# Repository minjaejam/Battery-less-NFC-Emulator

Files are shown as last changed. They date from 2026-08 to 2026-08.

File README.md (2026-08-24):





https://github.com/user-attachments/assets/a0f929fd-fd86-4b5f-9a33-4b0fc378b6a2

https://github.com/user-attachments/assets/47e20b58-1ad2-490b-87c6-6bac8df01a59

■ 주요 기능
1. 배터리 없이 동작
2. 13.56 MHz NFC 통신
3. MCU 기반 NFC 태그 에뮬레이션
4. ISO/IEC 14443 Type A 통신
5. PCB Loop Antenna 사용

■ 현재 지원
1. mifare classic 1k
2. ntag215 (시연을 위해 닌텐도 스위치 amiibo 데이터를 이용)

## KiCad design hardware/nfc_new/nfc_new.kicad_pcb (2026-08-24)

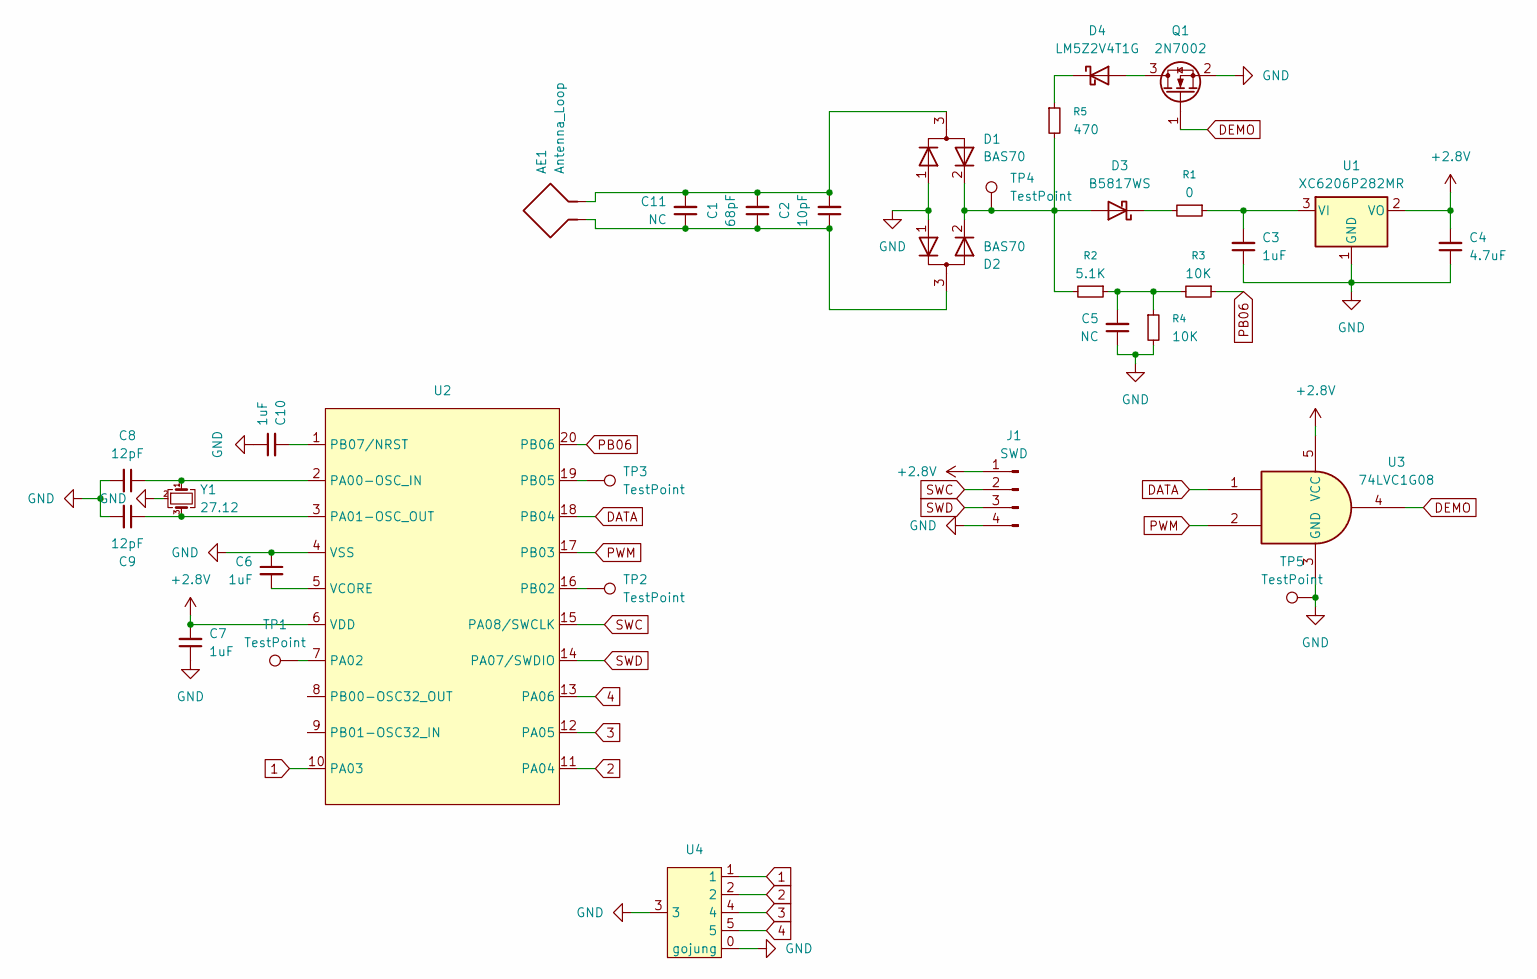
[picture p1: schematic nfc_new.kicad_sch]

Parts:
AE1: Antenna_Loop; 1.8uH_2
C1: 68pF; C_0805_2012Metric_Pad1.18x1.45mm_HandSolder
C2: 10pF; C_0805_2012Metric_Pad1.18x1.45mm_HandSolder
C3, C6, C7, C10: 1uF; C_0805_2012Metric_Pad1.18x1.45mm_HandSolder
C4: 4.7uF; C_0805_2012Metric_Pad1.18x1.45mm_HandSolder
C5, C11: NC; C_0805_2012Metric_Pad1.18x1.45mm_HandSolder
C8, C9: 12pF; C_0805_2012Metric_Pad1.18x1.45mm_HandSolder
D1, D2: BAS70; SOT-323_SC-70
D3: B5817WS; D_SOD-323_HandSoldering
D4: LM5Z2V4T1G; D_SOD-523
J1: SWD; PinHeader_1x04_P2.54mm_Vertical
Q1: 2N7002; SOT-23
R1: 0; R_0805_2012Metric_Pad1.20x1.40mm_HandSolder
R2: 5.1K; R_0805_2012Metric_Pad1.20x1.40mm_HandSolder
R3, R4: 10K; R_0805_2012Metric_Pad1.20x1.40mm_HandSolder
R5: 470; R_0805_2012Metric_Pad1.20x1.40mm_HandSolder
TP1, TP2, TP3, TP4, TP5: TestPoint; TestPoint_Pad_D1.0mm
U1: XC6206P282MR; SOT-23-3
U2: QFN-20-1EP_3x3mm_P0.4mm_EP1.65x1.65mm_ThermalVias
U3: 74LVC1G08; SOT-23-5_HandSoldering
U4: spd4
Y1: 27.12; Crystal_SMD_3225-4Pin_3.2x2.5mm_HandSoldering

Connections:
1: U2.10 (PA03), U4.1
2: U2.11 (PA04), U4.2
3: U2.12 (PA05), U4.4
4: U2.13 (PA06), U4.5
+2.8V: C4.2, C7.2, J1.1, U1.2 (VO), U2.6 (VDD), U3.5 (VCC)
DATA: U2.18 (PB04), U3.1
DEMO: Q1.1 (G), U3.4
GND: C3.1, C4.1, C5.1, C6.1, C7.1, C8.2, C9.2, C10.1, D1.1 (A), D2.1 (A), J1.4, Q1.2 (S), R4.2, TP5.1 (1_1), U1.1 (GND), U2.4 (VSS), U2.21 (VSS), U3.3 (GND), U4.0 (gojung), U4.3, Y1.2 (G), Y1.4 (G)
unnamed: C5.2, R2.1, R3.2, R4.1
unnamed: D1.2 (K), D2.2 (K), D3.2 (A), R2.2, R5.2, TP4.1 (1_1)
unnamed: AE1.2, C1.2, C2.2, C11.2, D1.3 (common)
unnamed: AE1.1, C1.1, C2.1, C11.1, D2.3 (common)
unnamed: D3.1 (K), R1.2
unnamed: D4.2 (A), Q1.3 (D)
unnamed: D4.1 (K), R5.1
unnamed: C3.2, R1.1, U1.3 (VI)
unnamed: C8.1, U2.2 (PA00-OSC_IN), Y1.1
unnamed: C9.1, U2.3 (PA01-OSC_OUT), Y1.3
unnamed: TP1.1 (1_1), U2.7 (PA02)
unnamed: TP2.1 (1_1), U2.16 (PB02)
unnamed: TP3.1 (1_1), U2.19 (PB05)
unnamed: C10.2, U2.1 (PB07/NRST)
unnamed: C6.2, U2.5 (VCORE)
PB06: R3.1, U2.20 (PB06)
PWM: U2.17 (PB03), U3.2
SWC: J1.2, U2.15 (PA08/SWCLK)
SWD: J1.3, U2.14 (PA07/SWDIO)

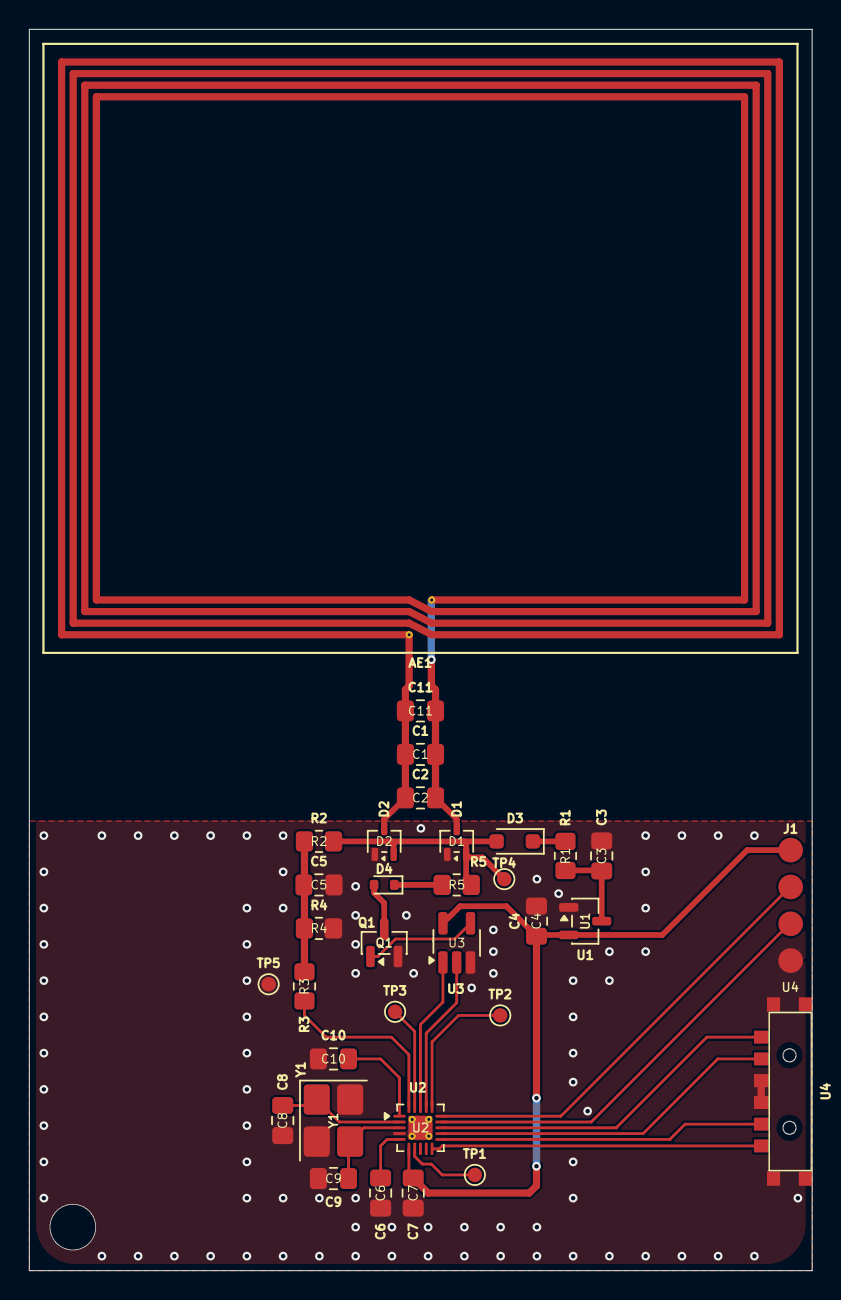
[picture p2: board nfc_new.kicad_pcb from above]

Board: 2 copper layers, 54.0 x 85.6 mm, 33 parts (0 on the bottom side), 27 nets.

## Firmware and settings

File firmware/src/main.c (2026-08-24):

#include <stddef.h>
#include <stdint.h>

#include "../inc/mifare_classic.h"
#include "../inc/tag_emulator.h"
#include "cw32l010.h"

#define REG32(address) (*(volatile uint32_t *)(uintptr_t)(address))

#define VC_DIV_REG          ((uintptr_t)&CW_VCREF->CR)
#define VC2_CR0_REG         ((uintptr_t)&CW_VC2->CR0)
#define VC2_CR1_REG         ((uintptr_t)&CW_VC2->CR1)
#define VC2_SR_REG          ((uintptr_t)&CW_VC2->SR)

#define NVIC_ISER0_REG      0xE000E100u
#define NVIC_ICPR0_REG      0xE000E280u
#define VC2_IRQ_MASK        (1u << 15)

#define SYSCTRL_CR0_REG     ((uintptr_t)&CW_SYSCTRL->CR0)
#define SYSCTRL_CR1_REG     ((uintptr_t)&CW_SYSCTRL->CR1)
#define SYSCTRL_HSE_REG     ((uintptr_t)&CW_SYSCTRL->HSE)
#define SYSCTRL_AHBEN_REG   ((uintptr_t)&CW_SYSCTRL->AHBEN)
#define SYSCTRL_APBEN2_REG  ((uintptr_t)&CW_SYSCTRL->APBEN2)
#define SYSCTRL_APBEN1_REG  ((uintptr_t)&CW_SYSCTRL->APBEN1)
#define SYSCTRL_HSE_STABLE  (1u << 19)
#define HSE_WAIT_FOR_STABLE 0
#define HSE_STARTUP_PDRIVER 7u
#define HSE_FAST_CONFIG     (0x00012605u | (HSE_STARTUP_PDRIVER << 20))


#define BTIM1_CR1_REG       ((uintptr_t)&CW_BTIM1->CR1)
#define BTIM1_ICR_REG       ((uintptr_t)&CW_BTIM1->ICR)
#define BTIM1_CNT_REG       ((uintptr_t)&CW_BTIM1->CNT)

#define GTIM1_CR1_REG       ((uintptr_t)&CW_GTIM1->CR1)
#define GTIM1_CCMR2CMP_REG  ((uintptr_t)&CW_GTIM1->CCMR2CMP)
#define GTIM1_CCER_REG      ((uintptr_t)&CW_GTIM1->CCER)
#define GTIM1_CNT_REG       ((uintptr_t)&CW_GTIM1->CNT)
#define GTIM1_PSC_REG       ((uintptr_t)&CW_GTIM1->PSC)
#define GTIM1_ARR_REG       ((uintptr_t)&CW_GTIM1->ARR)
#define GTIM1_CCR4_REG      ((uintptr_t)&CW_GTIM1->CCR4)

#define GPIOA_DIR_REG       ((uintptr_t)&CW_GPIOA->DIR)
#define GPIOA_OPENDRAIN_REG ((uintptr_t)&CW_GPIOA->OPENDRAIN)
#define GPIOA_PUR_REG       ((uintptr_t)&CW_GPIOA->PUR)
#define GPIOA_AFRL_REG      ((uintptr_t)&CW_GPIOA->AFRL)
#define GPIOA_ANALOG_REG    ((uintptr_t)&CW_GPIOA->ANALOG)
#define GPIOA_IDR_REG       ((uintptr_t)&CW_GPIOA->IDR)
#define GPIOA_BRR_REG       ((uintptr_t)&CW_GPIOA->BRR)

#define GPIOB_DIR_REG       ((uintptr_t)&CW_GPIOB->DIR)
#define GPIOB_OPENDRAIN_REG ((uintptr_t)&CW_GPIOB->OPENDRAIN)
#define GPIOB_AFRL_REG      ((uintptr_t)&CW_GPIOB->AFRL)
#define GPIOB_ANALOG_REG    ((uintptr_t)&CW_GPIOB->ANALOG)
#define GPIOB_BRR_REG       ((uintptr_t)&CW_GPIOB->BRR)

/* The scatter file fixes these objects because the recovered PHY uses them. */
uint32_t SystemCoreClock
    __attribute__((section(".bss.noinit.SystemCoreClock"), used));
NfcRuntime g_nfc_state
    __attribute__((section(".bss.noinit.g_nfc_state"), used));
typedef char nfc_runtime_size_check[(sizeof(NfcRuntime) == 0x108u) ? 1 : -1];
typedef char nfc_rx_offset_check[(offsetof(NfcRuntime, rx) == 8u) ? 1 : -1];

static void system_clock_start_hse(void)
{
    /* Start the crystal first, then do useful initialization while it locks. */
    REG32(SYSCTRL_AHBEN_REG) |= 0x30u;
    REG32(GPIOA_ANALOG_REG) = 3u;
    REG32(SYSCTRL_HSE_REG) = HSE_FAST_CONFIG;
    REG32(SYSCTRL_CR1_REG) |= 0x5A5A0182u;

    /* Make GPIO, GTIM1 and VC registers available during the HSE start-up. */
    REG32(SYSCTRL_AHBEN_REG) = 0x5A5A0032u;
    REG32(SYSCTRL_APBEN1_REG) = 0x5A5A0042u;
    REG32(SYSCTRL_APBEN2_REG) = 0x5A5A0004u;
}

static void system_clock_finish_hse(void)
{
#if HSE_WAIT_FOR_STABLE
    /* 8192 detected HSE clocks are required before the timing-source switch. */
    while ((REG32(SYSCTRL_HSE_REG) & SYSCTRL_HSE_STABLE) == 0u) {
    }
#endif

    REG32(SYSCTRL_CR0_REG) =
        (((REG32(SYSCTRL_CR0_REG) & 0xFFFFu) + 0x5A5A0000u) & ~7u) | 1u;
    SystemCoreClock = 27120000u;
    REG32(SYSCTRL_CR1_REG) =
        (((REG32(SYSCTRL_CR1_REG) & 0xFFFFu) + 0x5A5A0000u) & ~1u);
}

static void io_init(void)
{
    uint32_t selector;

    /* PB5/PB6 are unused analog inputs; do not power the former UART pins. */
    REG32(GPIOB_ANALOG_REG) = 0x60u;
    REG32(GPIOB_DIR_REG) = 0u;
    REG32(GPIOB_OPENDRAIN_REG) = 0u;
    REG32(GPIOB_BRR_REG) |= 0x18u;

    REG32(GPIOA_ANALOG_REG) &= ~0x7Cu;
    REG32(GPIOA_PUR_REG) |= 0x78u;
    REG32(GPIOA_DIR_REG) = (REG32(GPIOA_DIR_REG) & ~0x04u) | 0x78u;
    REG32(GPIOA_OPENDRAIN_REG) &= ~0x04u;
    REG32(GPIOA_BRR_REG) = 0x04u;

    selector = REG32(GPIOA_IDR_REG) & 0x78u;
    REG32((uintptr_t)&g_nfc_state) = 0x01000000u;
    g_nfc_state.printf_state = 0u;

    /* Patterns are written in PA3, PA4, PA5, PA6 order. */
    switch (selector) {
    case 0x70u: /* 0,1,1,1: PA3 low */
        g_nfc_state.slot = 4u;
        break;
    case 0x68u: /* 1,0,1,1: PA4 low */
        g_nfc_state.slot = 5u;
        break;
    case 0x58u: /* 1,1,0,1: PA5 low */
        g_nfc_state.slot = 6u;
        break;
    case 0x38u: /* 1,1,1,0: PA6 low */
        g_nfc_state.slot = 7u;
        break;
    default:
        g_nfc_state.slot = 4u;
        g_nfc_state.selector_valid = 0u;
        break;
    }

    /* The one-hot selector is latched. Remove its static pull-up current. */
    REG32(GPIOA_PUR_REG) &= ~0x78u;
    REG32(GPIOA_ANALOG_REG) |= 0x78u;

    REG32(GPIOB_AFRL_REG) =
        (REG32(GPIOB_AFRL_REG) & 0xFFFFF8FFu) + 0x00000400u;
}

static void nfc_config_typea_timing(void)
{
    REG32(GPIOB_AFRL_REG) =
        (REG32(GPIOB_AFRL_REG) & ~(7u << 12)) | (3u << 13);
    REG32(GTIM1_CR1_REG) = 0x86u;
    REG32(GTIM1_PSC_REG) = 0u;
    REG32(GTIM1_CCMR2CMP_REG) |= ((uint32_t)GTIM1_BASE << 2);
    REG32(GTIM1_ARR_REG) = 0x1Fu;
    REG32(GTIM1_CCR4_REG) = 0x0Fu;
    REG32(GTIM1_CNT_REG) = 0x18u;
    REG32(GTIM1_CCER_REG) |= ((uint32_t)GTIM1_BASE >> 18);
}

static void nfc_clear_timing_state(void)
{
    REG32(BTIM1_CR1_REG) = 0u;
    REG32(BTIM1_ICR_REG) = 0u;
    REG32(BTIM1_CNT_REG) = 0u;
}

static void nfc_enable_typea_receiver(void)
{
    REG32(VC2_CR1_REG) = 0x57u;
    REG32(VC_DIV_REG) = 0x16u;
    REG32(VC2_SR_REG) &= ~1u;
    REG32(NVIC_ICPR0_REG) = VC2_IRQ_MASK;
    REG32(NVIC_ISER0_REG) = VC2_IRQ_MASK;
    REG32(VC2_CR0_REG) = 0x31Fu;
}

int main(void)
{
    uint8_t mfc_selected;
    uint8_t ntag_selected;

    system_clock_start_hse();
    io_init();
    nfc_config_typea_timing();
    nfc_clear_timing_state();

    mfc_selected = (uint8_t)((g_nfc_state.selector_valid != 0u) &&
                            (g_nfc_state.slot == MFC1K_SLOT_INDEX));
    ntag_selected = (uint8_t)((g_nfc_state.selector_valid != 0u) &&
                             (g_nfc_state.slot != MFC1K_SLOT_INDEX));
    if (mfc_selected != 0u) {
        mifare_classic_memory_prepare();
    } else if (ntag_selected != 0u) {
        ntag_memory_prepare();
    }

    system_clock_finish_hse();
    nfc_enable_typea_receiver();

    if (mfc_selected != 0u) {
        mifare_classic_memory_finish();
    }

    for (;;) {
        __WFI();
    }
}

void assert_failed(uint8_t *file, uint32_t line)
{
    (void)file;
    (void)line;
    for (;;) {
    }
}

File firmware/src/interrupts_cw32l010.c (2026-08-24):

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

/* Includes ------------------------------------------------------------------*/
#include "../inc/interrupts_cw32l010.h"
/* External variables --------------------------------------------------------*/
/* USER CODE BEGIN EV */
/* VC2_IRQHandler is implemented directly in nfc_irq.s. */
/* USER CODE END EV */


/******************************************************************************/
/*           Cortex-M0P Processor Interruption and Exception Handlers          */
/******************************************************************************/
/**
  * @brief This function handles Non maskable interrupt.
  */
void NMI_Handler(void)
{
}

/**
  * @brief This function handles Hard fault interrupt.
  */
void HardFault_Handler(void)
{
    while (1)
    {
    }
}


/**
  * @brief This function handles System service call via SWI instruction.
  */
void SVC_Handler(void)
{
}


/**
  * @brief This function handles Pendable request for system service.
  */
void PendSV_Handler(void)
{
}


/******************************************************************************/
/* CW32L010 Peripheral Interrupt Handlers                                     */
/* Add here the Interrupt Handlers for the used peripherals.                  */
/* For the available peripheral interrupt handler names,                      */
/* please refer to the startup file (startup_cw32l010.s).                     */
/******************************************************************************/

/**
 * @brief This funcation handles WDT
 */
void WDT_IRQHandler(void)
{
    /* USER CODE BEGIN */

    /* USER CODE END */
}

/**
 * @brief This funcation handles LVD
 */
void LVD_IRQHandler(void)
{
    /* USER CODE BEGIN */

    /* USER CODE END */
}

/**
 * @brief This funcation handles RTC
 */
void RTC_IRQHandler(void)
{
    /* USER CODE BEGIN */

    /* USER CODE END */
}

/**
 * @brief This funcation handles FLASHRAM
 */
void FLASHRAM_IRQHandler(void)
{
    /* USER CODE BEGIN */

    /* USER CODE END */
}

/**
 * @brief This funcation handles SYSCTRL
 */
void SYSCTRL_IRQHandler(void)
{
    /* USER CODE BEGIN */

    /* USER CODE END */
}

/**
 * @brief This funcation handles GPIOA
 */
void GPIOA_IRQHandler(void)
{
    /* USER CODE BEGIN */

    /* USER CODE END */
}

/**
 * @brief This funcation handles GPIOB
 */
void GPIOB_IRQHandler(void)
{
    /* USER CODE BEGIN */

    /* USER CODE END */
}


/**
 * @brief This funcation handles ADC
 */
void ADC_IRQHandler(void)
{
    /* USER CODE BEGIN */

    /* USER CODE END */
}

/**
 * @brief This funcation handles ATIM
 */
void ATIM_IRQHandler(void)
{
    /* USER CODE BEGIN */

    /* USER CODE END */
}

/**
 * @brief This funcation handles VC1
 */
void VC1_IRQHandler(void)
{
    /* USER CODE BEGIN */

    /* USER CODE END */
}

/**
 * @brief This funcation handles GTIM1
 */
void GTIM1_IRQHandler(void)
{
    /* USER CODE BEGIN */

    /* USER CODE END */
}

/**
 * @brief This funcation handles LPTIM
 */
void LPTIM_IRQHandler(void)
{
    /* USER CODE BEGIN */

    /* USER CODE END */
}

/**
 * @brief This funcation handles BTIM1
 */
void BTIM1_IRQHandler(void)
{
    /* USER CODE BEGIN */

    /* USER CODE END */
}

/**
 * @brief This funcation handles BTIM2
 */
void BTIM2_IRQHandler(void)
{
    /* USER CODE BEGIN */

    /* USER CODE END */
}

/**
 * @brief This funcation handles BTIM3
 */
void BTIM3_IRQHandler(void)
{
    /* USER CODE BEGIN */

    /* USER CODE END */
}

/**
 * @brief This funcation handles I2C1
 */
void I2C1_IRQHandler(void)
{
    /* USER CODE BEGIN */

    /* USER CODE END */
}

/**
 * @brief This funcation handles SPI1
 */
void SPI1_IRQHandler(void)
{
    /* USER CODE BEGIN */

    /* USER CODE END */
}

/**
 * @brief This funcation handles UART1
 */
void UART1_IRQHandler(void)
{
    /* USER CODE BEGIN */

    /* USER CODE END */
}

/**
 * @brief This funcation handles UART2
 */
void UART2_IRQHandler(void)
{
    /* USER CODE BEGIN */

    /* USER CODE END */
}


/**
 * @brief This funcation handles FAULT
 */
void CLKFAULT_IRQHandler(void)
{
    /* USER CODE BEGIN */

    /* USER CODE END */
}

/************************ (C) COPYRIGHT CW *****END OF FILE****/

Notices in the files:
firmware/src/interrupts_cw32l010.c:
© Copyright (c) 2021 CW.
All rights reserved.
